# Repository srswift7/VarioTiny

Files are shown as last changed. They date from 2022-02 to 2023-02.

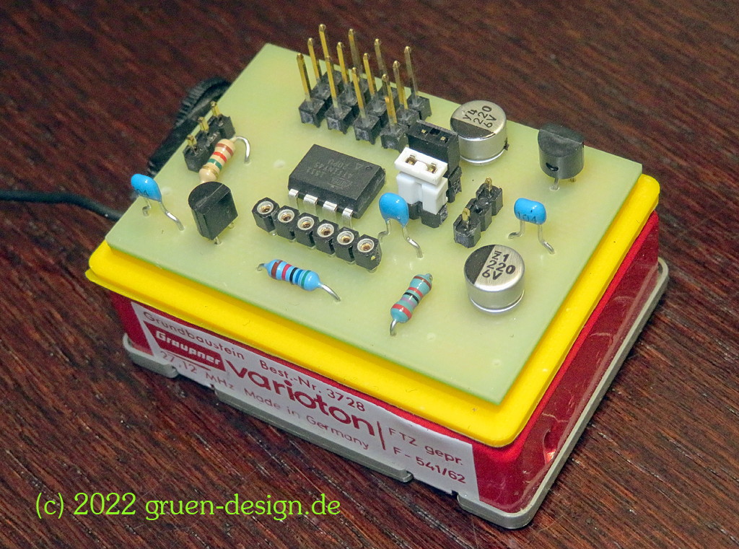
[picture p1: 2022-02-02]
IMG_4509.jpg

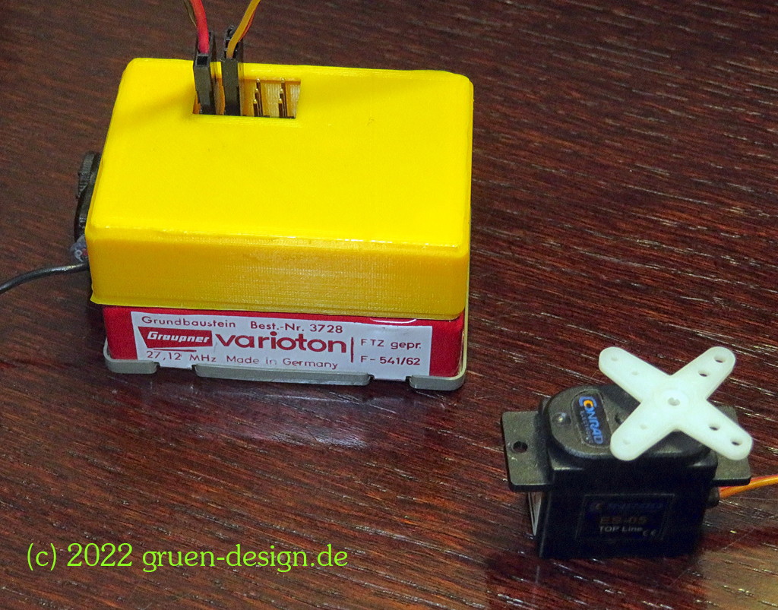
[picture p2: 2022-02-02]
IMG_4507.jpg

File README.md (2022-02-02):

# VarioTiny
Universelle Schaltstufe für Tipp-Anlagen

Bei all der Beschäftigung mit der "guten Alten Zeit" und der Fernsteuerungstechnik aus den Jugendjahren kam der Wunsch auf, es noch einmal mit einer Tipp-Anlage zu versuchen. Die 27 MHz-Technik ist ja immer noch geduldet. Und die Konkurrenz im Äther (CB-Funk, Garagentoröffner, Spielzeuge, Babyphons) gibt es ja fast nicht mehr. Es sollte doch eigentlich nichts dagegen sprechen.

Nur, die historischen Servos hatte ich in schlechter Erinnerung. Groß, schwer, stromhungrig und unzuverlässig. Wenn mich meine Erinnerungen nicht täuschen. Wie wäre es, halbwegs moderne Servos an eine Tipp-Anlage anzuschließen?

Gesagt, getan. Nach einigen mehr oder weniger ernstgemeinten Gedanken und einigen bierförmigen Ideenbeschleunigern entstand meine VarioTiny-Schaltstufe.

Diese passt auf die weit verbreiteten Varioton-Empfänger. Ist aber prinzipiell auch mit jedem anderen Empfänger verwendbar. Und erlaubt den Anschluss von bis zu drei Servos oder auch anderen "Standard"-Komponenten. Wie z.B. einem Fahrregler.

Das Herz des ganzen ist ein ATTiny45-Mikrocontroller. Die Schaltung selbst ist recht simpel. Ein Spannungsregler sorgt für maximal 5V am Chip. Eine Transistorstufe passt die Empfängersignale an den Controller an. Der Rest geschieht durch Software.

Mit den beiden Jumpern kann ich einstellen, woher der Empfänger seinen Saft bekommt und ob Servos und Empfänger aus einem Akku gespeist werden sollen. Das Gehäuse ist 3D-gedruckt.

Die Feinabstimmung der Tonfrequenzen geschieht durch "Lernen". Hat nichts mit KI zu tun, sondern mit einem speziellen Stecker auf einem der Servoanschlüsse schaltet die Schaltstufe in den Programmiermodus, misst die empfangene NF und speichert die Frequenz im EEPROM. Damit kann auch die Servozuordnung und Steilrichtung einfach eingestellt werden. Auch lassen sich damit andere Tonfrequenzsender einfach zuordnen. Und das ganze kann beliebig oft wiederholt werden.

Für die Motordrossel ist ein "nichtneutralisierender" Kanal mit 8 Zwischenpositionen programmiert.

Den ATTiny45 hab ich in BASCOM programmiert, das Programm belegt 95% der 4kByte.
Die Servos verhalten sich von der Steilgeschwindigkeit fast wie die Bellamatk-Rudermaschinen.
Der Mikrocontroller generiert an den 3 Servoausgängen den üblichen Servoimpuls von 1.5ms. Und misst die Frequenz des hereinkommenden Tonsignals, wenn es zu einer (vorher gespeicherten) Frequenz passt, wird der Servoimpuls am entsprechenden Ausgang um 0.5ms vergrößert oder verkleinert. Das gilt für die Kanäle Seite und Höhe. Für die Motordrossel wird beim passenden Ton der Servoimpuls in insgesamt 8 Stufen vergrößert oder verkleinert.
Wenn nur 4 Tonfrequenzen gespeichert sind, kann man mit den Tönen 3 und 4 wahlweise ein (Höhen-)Ruder ("neutralisierend") oder die Motordrossel ("nichtneutralisierend") steuernd. Sind nur 3 Kanäle "gelernt" steuert der 3. Kanal das Servo wie ein Schaltstern. Ein mal tasten rückt das Servo in der Sequenz "Neutral - links - Neutral - rechts - neutral" weiter.

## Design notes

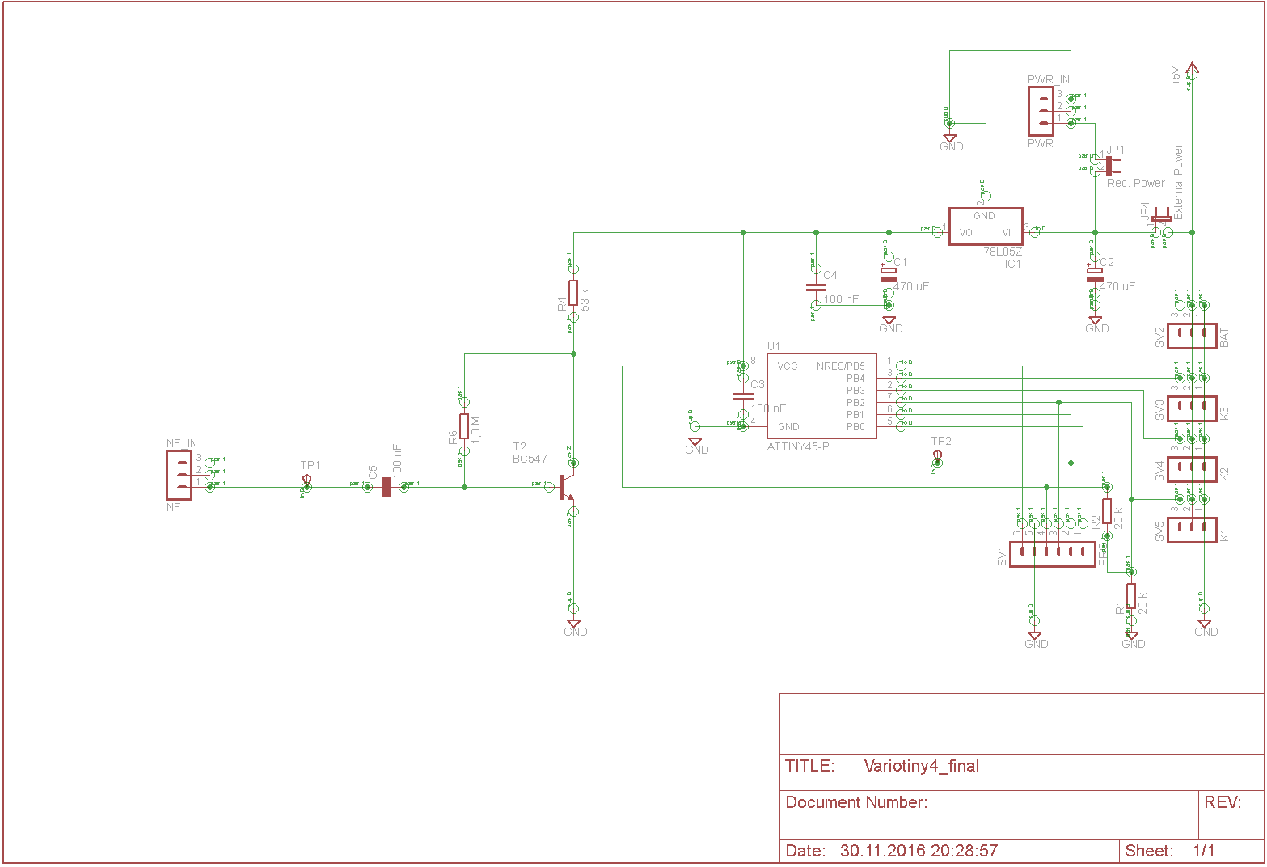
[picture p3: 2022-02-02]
Variotiny4.png

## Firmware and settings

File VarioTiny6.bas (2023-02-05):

' ##########################################################
' #
' # VARIOTINY 6
' #
' #                          (c) gruen-design.de 2015-2022
' #
' ##########################################################

' Eine universelle Tipp-Schaltstufe für Prop-Servos

' Am Eingang PB1 eines Attiny45 liegt eine NF zwischen 500Hz und 10kHz an.
' Am Besten natürlich schon in Rechteckform

' Der Komparator mach daraus Flanken, der Zeitabstand zwischen 2 0-1 - Flanken wird gemessen
' Die Daraus bestimmte Frequenz wird mit einer im EEPROM gespeicherten Vergleichsliste
' verglichen, bei übereinstimmung wird der Kanalimpuls von bis zu 3 angeschlossenen
' Servos (PB2, PB3, PB4) zwischen links / Mitte / rechts modifiziert

' Die Zuordnung der Servos zu den Tonfrequenzen kann in einem Lernmodus zugeordnet werden.
' Dazu ist vor dem Einschalten der PB2 mit 5+ zu verbinden. Bei jeder erkannten stabilen Tonfrequenz
' Wird das Servo an PB3 ein kurzer Ausschlag erzeugt.

' Wenn beim Einschalten der PB2 frei ist, oder mit einem Servo verbunden, wird nach der Initialisierung
' Die Anzahl der zugeordneten Tonfrequenzen als Servobewegungen an PB3 ausgegeben.

' PB4 ist als Motordrossel geschaltet, jeder Impuls auf K3 / K5 erhöht die Motordrehzahl (8 Stufen bis Vollgas)
' jeder Impuls auf K4 / K6 verringert die Drehzahl

' Im Falle des Dreikanalbetriebes ist der Servoanschluss an PB4 als Schaltstern
' programmiert mit der Impulsfolge  => links, Mitte, Rechts, Mitte, Links

'---------------------------------------------------------


$prog &HFF , &HE2 , &HDF , &HFF                  ' Take care that the chip supports all fuse bytes.

$regfile = "ATtiny45.DAT"                        ' ATTiny / ATmega8-Deklarationen
' $crystal = 3686400                             ' Quarz: 3,6864 MHz
$crystal = 8000000                               ' Kein Quarz, 8MHz


Const TOLERANZ = 3


Declare Sub Flanke()                             ' Callback fuer Frequenzmessung (Timer0, ACI)
Declare Sub Ms20_loop()                          ' Callback fuer 20ms Loop, (Timer 1, ueberlauf)
Declare Sub Beep()                               ' Kurz mit einem Servo wedeln
Declare Sub Lernen()
Declare Sub Analyze_sr()
Declare Sub Sr_in(byval Zeit As Byte)
Declare Sub Kanalimpulse()

Declare Function ober_limit(byval Zahl As Byte) As Byte
Declare Function unter_limit(byval Zahl As Byte) As Byte
Declare Function match(byval Zahl As Byte) As Byte

Dim Zahl As Byte
Dim Zu As Byte
Dim Zo As Byte

Dim Sregister(10) As Byte  ' Hier laufen die gemessenen Tonfrequenzen ein (Zeit zwischen 2 Flanken
Dim Kregister(10) As Byte  ' Hier sind die "gematchten" letzten 10 Kanäle

Dim Decision(6) As Byte

' Dim Kanal As Byte

Dim Semaph As Bit
Dim Neutral As Bit
Dim Ncount As Byte
Dim Direction As Bit
Dim Motor As Byte

Dim Uu As Integer

Dim Lernmod As Bit

Dim Ii As Integer

' Die Permanenten Kanalspeicher
Dim Ekan As Eram Byte
Dim Ee_k(6) As Eram Byte

Dim Lkan As Byte
Dim Iii As Byte

' Die Grenzwerte
Dim U_k(6) As Byte
Dim O_k(6) As Byte

Dim Copyright As String * 26

' Das ist einfach nur, damit man diese schöne Zeichenkette im Flash sehen kann
Copyright = "c( )rgeu-nedisngd. e0232"

Dim Uhr_an As Bit
' Dim Count As Byte

Ddrb = &B00011100                                ' Pin PB2-4 als Ausgang konfigurieren
Portb = &B00000000                               ' Ausgaenge auf 0, kein pullup

' Und dann noch der Komparator, (D7)
Acsr = &B01001011                                ' Interne Referenz

' Nein, wir zählen nicht, wir stoppen die Zeit von Flanke zu Flanke. Dazu nehmen wir den Timer0

' Timer zum stoppen der Zeit zwischen 2 Flanken
On Aci Flanke
Config Timer0 = Timer , Prescale = 64            ' Timer-Takt ist Quarz/64,
                                                 ' bei 8MHz Takt hat der Timer dann 125 kHz
                                                 ' Das bedeutet 12.5 ticks bei 10 kHz Tonfrequenz

Timer0 = 0
Uhr_an = 0

Semaph = 0
' Fuer die 20ms nehmen wir einen 2. Timer

Config Timer1 = Timer , Prescale = 1024          ' Timer-Takt ist Quarz/1024
On Timer1 Ms20_loop

Enable Timer1                                    ' Timer0-Overflow-Interrupt ein
' Takt/1024 = 3600 Hz
'         72 Zähltakte (3.6 MHz)
' 20 ms = 125 Zähltakte  (6.4MHz)
'          156 Zähltakte (8MHz)
Timer1 = 100                                     ' 256 - x

Disable Interrupts                               ' Interrupts erst einmal global verhindern

Waitms 1000

Lernmod = 0                                      ' Den Lernmodus erkennen wir (nachher) an einer Drahtbrücke
Zahl = 0
' Kanal = 0

' Am Anfang prüfen wir mit Pin B2, ob wir im Programmiermodus sind
' Dazu programmieren wir den Pin auf Eingang ohne Pull-Up. Wir ziehn den Pin extern mit 20k auf Masse.
' Zum Programmieren legen wir ihn auf 5V

Ddrb.2 = 0                                        ' Eingang
Portb.2 = 0                                       ' Kein Pull UP für B2

' Abfrage Pin B2 - sind wir im Programmiermodus?

Lernmod = Pinb.2

If Lernmod = 1 Then
   Ekan = 0

   Wait 5
   Call Beep
Else
   ' Wir programmieren jetzt nicht, also B2 ist ein Ausgang wie alle anderen auch.
   Ddrb.2 = 1                                     ' Ausgang
   Portb.2 = 0                                    ' Low B2

   ' Basisvoreinstellung, der Chip ist noch nicht belernt
   ' Geteste wurde mit folgenden Sendern:

   If Ekan < 1 Or Ekan > 6 Then                   ' Es wurde noch nicht gelernt, Voreinstellung in den EEPROM
     ' Pilot-4
     Ee_k(1) = 68       ' Pilot-4 K1
     Ee_k(2) = 47       ' Pilot-4 K2
     Ee_k(3) = 95       ' Pilot-4 K3
     Ee_k(4) = 32       ' Pilot-4 K4
     Ekan = 4

     ' Varioton S (4-Kanal)
     ' Ee_k(1) = 155   ' Varioton K1
     ' Ee_k(2) = 115   ' Varioton K2
     ' Ee_k(3) = 75    ' Varioton K3
     ' Ee_k(4) = 55    ' Varioton K4
     ' Ekan = 4

     ' Mecatron - 3
     ' Ee_k(1) = 56   ' Mecatron K1
     ' Ee_k(2) = 46   ' Mecatron K2
     ' Ee_k(3) = 38   ' Mecatron K3
     ' Ekan = 3

     ' Junior-5
     ' Ee_k(1) = 34   ' Junior-5 K1
     ' Ee_k(2) = 42   ' Junior-5 K2
     ' Ee_k(3) = 51   ' Junior-5 K3
     ' Ee_k(4) = 63   ' Junior-5 K4
     ' Ee_k(5) = 82   ' Junior-5 K5
     ' Ekan = 5
   End If
   
   ' Initialisierung, lesen wir die Kanalwerte aus dem EEPROM und berechnen die Grenzen
   ' Wir berechnen die Toleranzbereiche der Tonfrequenzen aus dem gelernten Mittelwert +-TOLERANZ
   Lkan = Ekan
   For Ii = 1 To Lkan
     U_k(Ii) = unter_limit(Ee_k(Ii))
     O_k(Ii) = ober_limit(Ee_k(Ii))
   Next Ii

   ' Ausgabe : Wieviel Kanäle haben wir denn ?
   Lkan = Ekan
   For Iii = 1 To Lkan
     Call Beep
     Waitms 100
   Next

End If


'---------------------------------------------------------

Enable Interrupts                                           'Interrupts global zulassen
' doppelt?
Sreg.7 = 1                                                  'Interrupts global einschalten

Direction = 1

Do                                                          'Hauptschleife
Loop
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

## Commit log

2022-02-02 Eagle File der Leiterplatte
    [Variotiny4_v3.brd]
2023-01-13 Minor Fixes
    Tonfrequenzbereich nach unten erweitert um K1+2 der VARIOPHON zu erkennen
    Code bereioigt
    [VarioTiny6.bas]
2023-01-16 Refactoring Kanalimpulsgenerierung
    Fehlertoleranz, zwei Tongeneratoren (einfacher Simultanbetrieb) sollte damit möglich sein, Entprellung der Motorfunktion verbessert
